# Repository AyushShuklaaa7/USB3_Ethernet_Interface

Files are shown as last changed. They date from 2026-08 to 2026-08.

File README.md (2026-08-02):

# USB 3.1 Gen 1 to Gigabit Ethernet Interface

This project is a hardware implementation of a USB 3.1 Gen 1 to Gigabit Ethernet adapter designed in KiCad. It is based on the Microchip LAN7801 USB-to-Ethernet controller and the KSZ9031RNX Gigabit Ethernet PHY.

The goal of this project was to gain practical experience in designing a high-speed PCB while following signal integrity, power integrity, and layout guidelines required for USB 3.1 and Gigabit Ethernet interfaces.

---

# Overview

The LAN7801 acts as the USB 3.1 Gen 1 bridge and Ethernet MAC, converting 5 Gbps USB SuperSpeed data into a 125 MHz RGMII interface. The KSZ9031RNX then converts the RGMII data into standard Gigabit Ethernet signals that are transmitted through the RJ45 MagJack.

The design uses dedicated 3.3V and 1.2V power rails. Instead of using an external 1.2V regulator, the KSZ9031RNX's integrated LDO controller is used with a DMG2301L P-channel MOSFET to generate the PHY core supply, reducing the overall component count.

A 25 MHz ABM8G crystal provides the reference clock for both devices.

---

# PCB Layout

### Top Layer

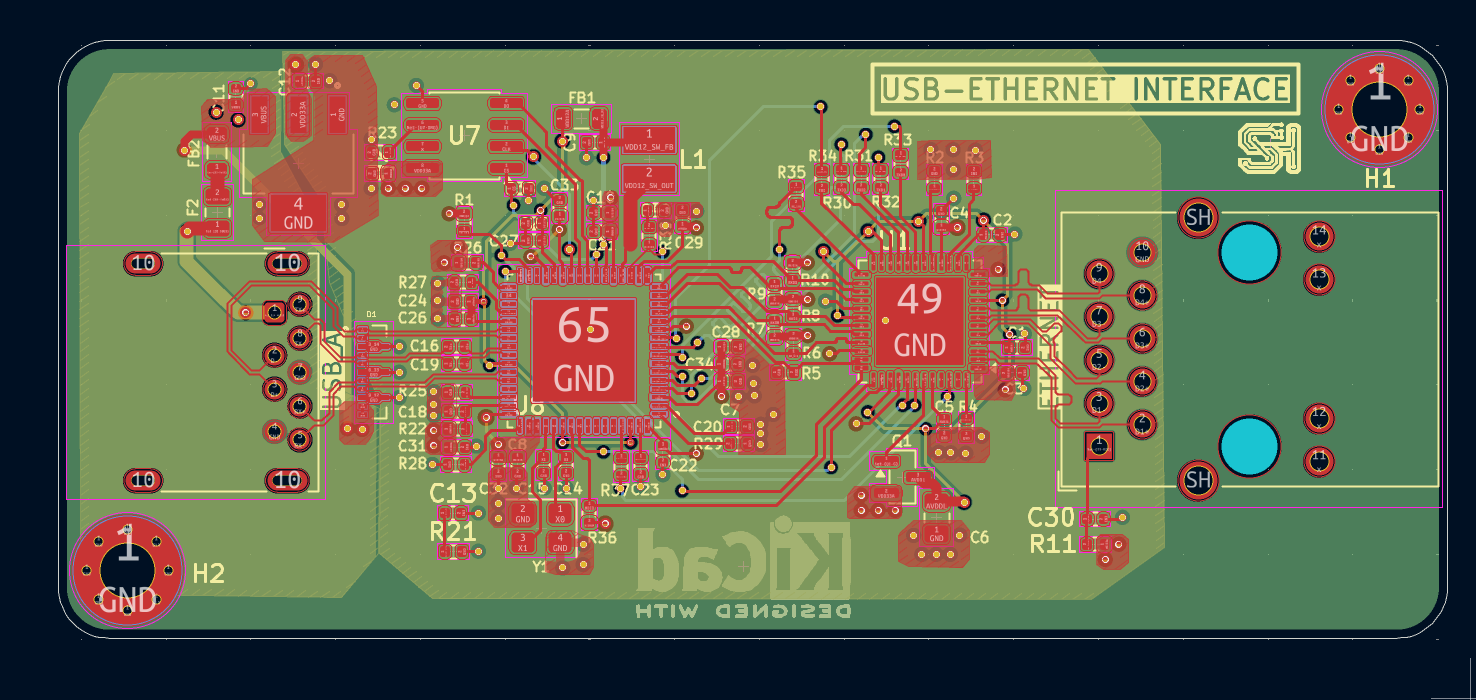
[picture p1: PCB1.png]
Top Layer


---

### Bottom Layer

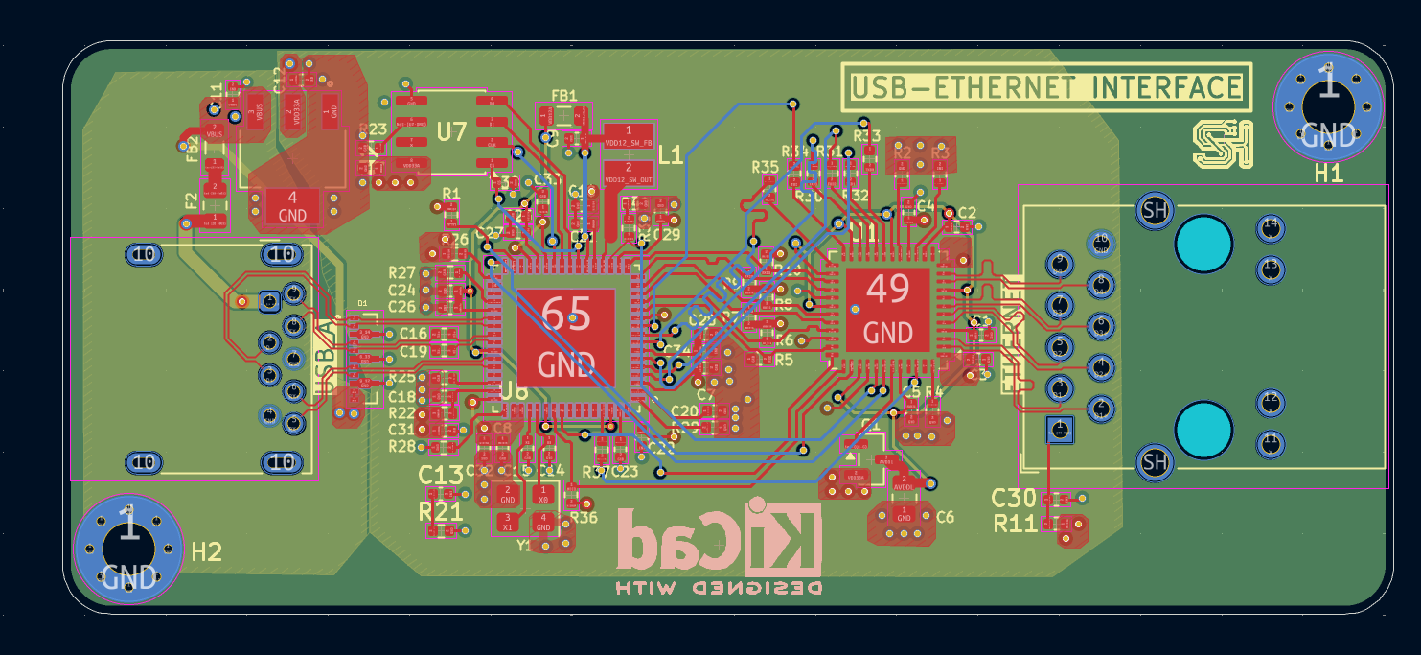
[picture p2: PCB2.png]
Bottom Layer


---

### 3D View

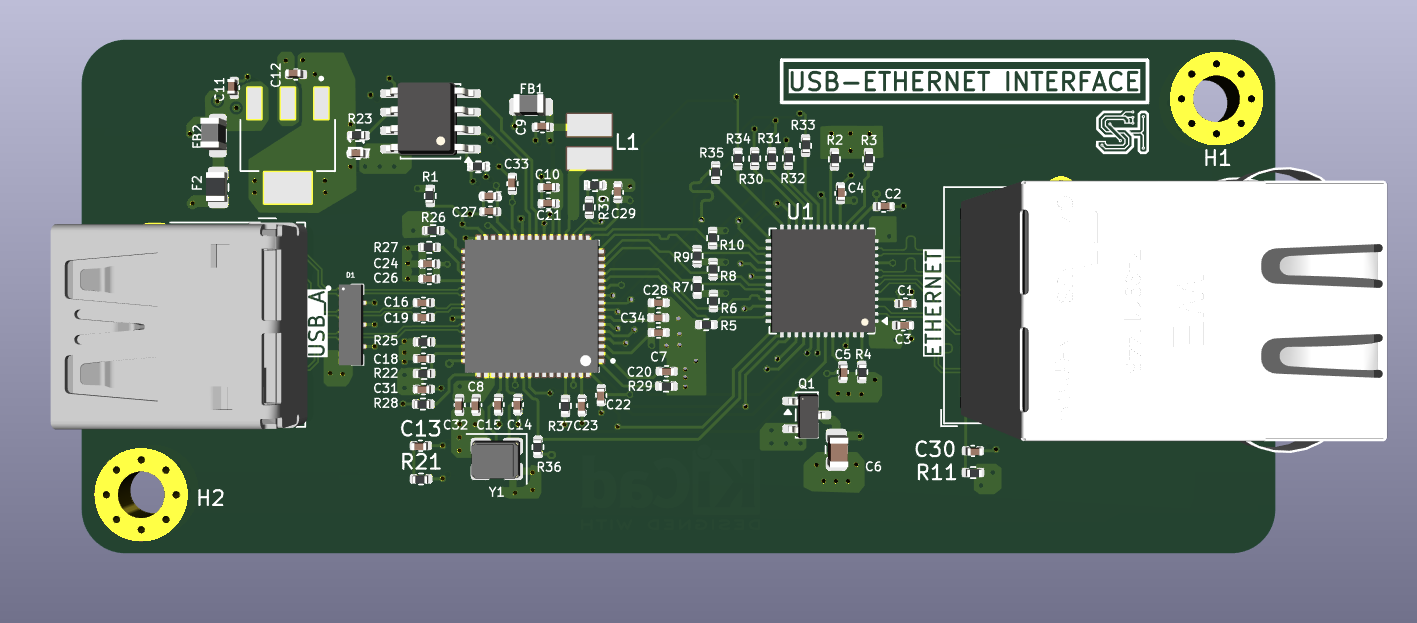
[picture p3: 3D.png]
3D View


---

# Hardware Block Diagram

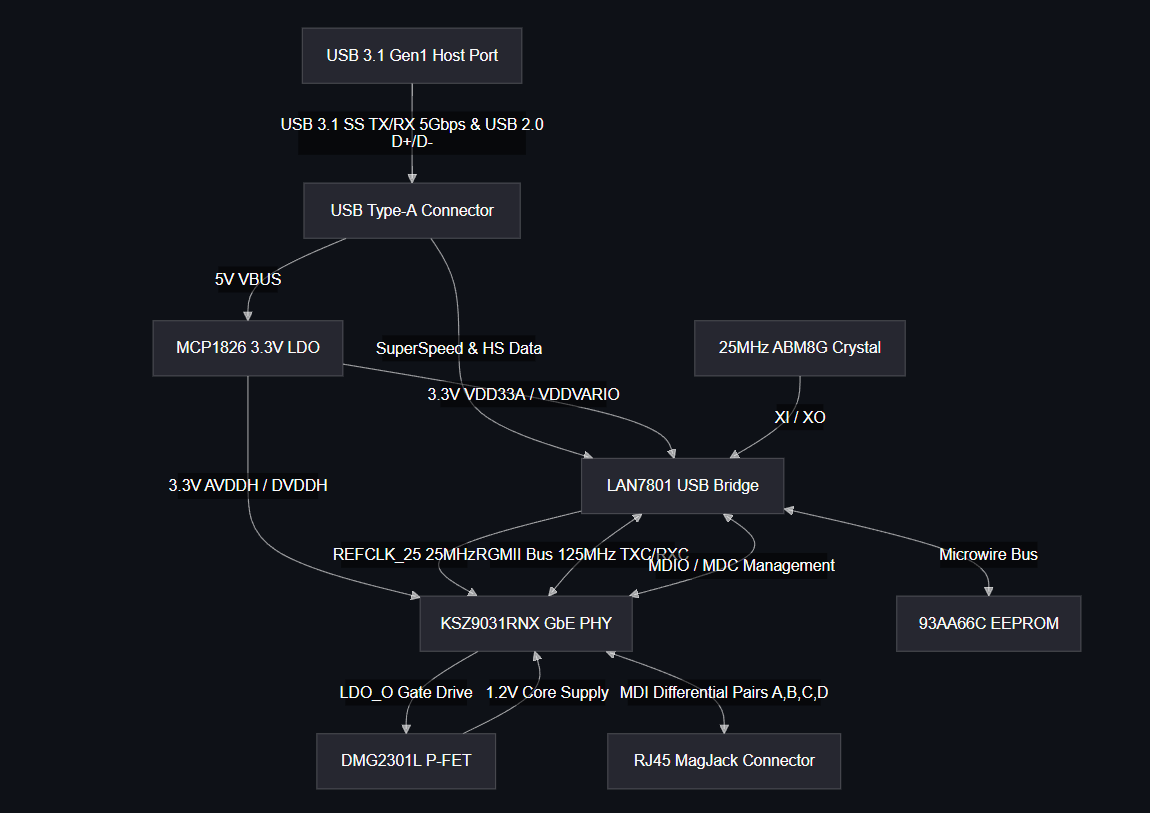
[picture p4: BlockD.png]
Block Diagram


The USB Type-A connector interfaces with the LAN7801 controller. The controller communicates with the KSZ9031RNX Gigabit PHY over the RGMII interface, while MDIO/MDC is used for PHY configuration. The PHY then drives the RJ45 MagJack to provide a standard Gigabit Ethernet connection.

---

# Design Approach

The project started by studying the LAN7801 and KSZ9031RNX datasheets along with the manufacturer's reference designs to understand the required interfaces, power supplies, clocking, and layout recommendations.

After completing the schematic, component placement was planned carefully to keep high-speed signal paths as short as possible. The USB controller was placed close to the USB connector, while the Ethernet PHY was positioned near the RJ45 MagJack to minimize RGMII routing.

During PCB layout, the main focus was maintaining signal integrity by following controlled impedance routing, differential pair routing, length matching, proper grounding, and good decoupling practices.

---

# Main Components

| Component | Description |
|---|---|
| LAN7801 | USB 3.1 Gen 1 to Gigabit Ethernet Controller |
| KSZ9031RNX | Gigabit Ethernet PHY |
| ABM8G | 25 MHz Crystal Oscillator |
| DMG2301L | P-Channel MOSFET |
| RJ45 MagJack | Gigabit Ethernet Connector |
| USB Type-A Connector | USB SuperSpeed Interface |

---

# PCB Design Highlights

- 4-layer PCB stack-up
- USB 3.1 SuperSpeed differential pair routing
- 125 MHz RGMII interface routing
- Controlled impedance traces
- Differential pair length matching
- Continuous ground plane
- Proper decoupling capacitor placement
- ESD protection for external interfaces
- Power integrity considerations

---

# Design Challenges

Some of the key challenges while designing this PCB were:

- Routing USB SuperSpeed differential pairs while maintaining impedance.
- Length matching the RGMII interface.
- Placing decoupling capacitors close to the IC power pins.
- Maintaining clean return current paths using continuous ground planes.
- Planning the component placement to minimize high-speed routing complexity.
- Following the layout recommendations provided in the component datasheets.

---

# Software Used

- KiCad
- Saturn PCB Toolkit
- Pspice

---

# Future Improvements

- Generate complete fabrication outputs (Gerber, Drill, BOM and Pick & Place files).
- Perform impedance verification using PCB stack-up calculations.
- Prototype and validate the hardware with functional testing.
- Perform USB and Ethernet compliance testing.

---

# Author

**Ayush Shukla**

B.Tech Electronics & Telecommunication Engineering

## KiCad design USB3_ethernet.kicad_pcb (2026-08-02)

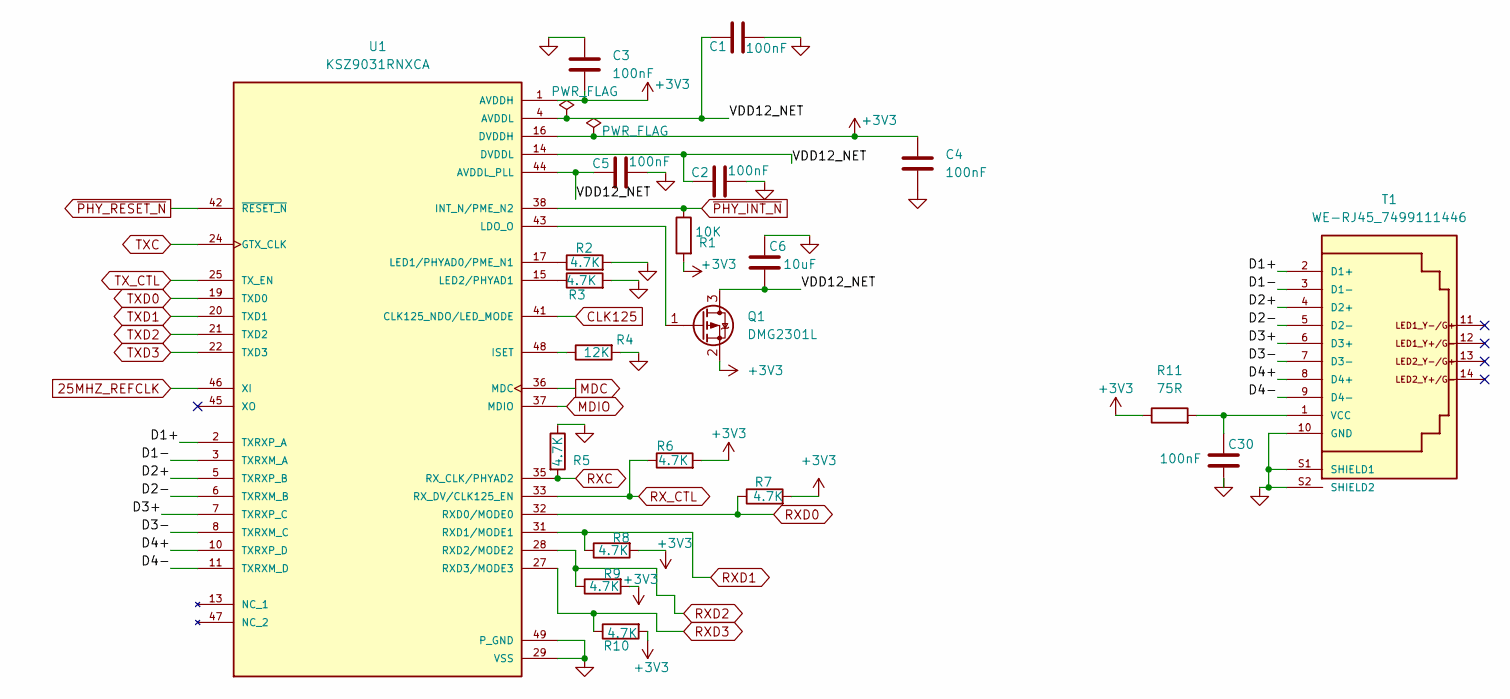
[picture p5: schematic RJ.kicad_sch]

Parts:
C1, C2, C3, C4, C5, C30: 100nF; C_0402_1005Metric
C6: 10uF; C_0805_2012Metric
Q1: DMG2301L; SOT-23
R1: 10K; R_0402_1005Metric
R2, R3, R5, R6, R7, R8, R9, R10: 4.7K; R_0402_1005Metric
R4: 12K; R_0402_1005Metric
R11: 75R; R_0402_1005Metric
T1: WE-RJ45_7499111446; RJ45_Wuerth_7499111446_Horizontal
U1: KSZ9031RNXCA; QFN-48-1EP_7x7mm_P0.5mm_EP5.15x5.15mm; PARTREV 07-09-24

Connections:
25MHZ_REFCLK: U1.46 (XI); also elsewhere on the board
/RJ/D1+: T1.2 (D1+), U1.2 (TXRXP_A); also elsewhere on the board
/RJ/D1-: T1.3 (D1-), U1.3 (TXRXM_A); also elsewhere on the board
/RJ/D2+: T1.4 (D2+), U1.5 (TXRXP_B); also elsewhere on the board
/RJ/D2-: T1.5 (D2-), U1.6 (TXRXM_B); also elsewhere on the board
/RJ/D3+: T1.6 (D3+), U1.7 (TXRXP_C); also elsewhere on the board
/RJ/D3-: T1.7 (D3-), U1.8 (TXRXM_C); also elsewhere on the board
/RJ/D4+: T1.8 (D4+), U1.10 (TXRXP_D); also elsewhere on the board
/RJ/D4-: T1.9 (D4-), U1.11 (TXRXM_D); also elsewhere on the board
AVDDL: C1.1, C2.1, C5.1, C6.2, Q1.3 (D), U1.4 (AVDDL), U1.9 (AVDDL), U1.14 (DVDDL), U1.18 (DVDDL), U1.23 (DVDDL), U1.26 (DVDDL), U1.30 (DVDDL), U1.39 (DVDDL), U1.44 (AVDDL_PLL)
CLK125: U1.41 (CLK125_NDO/LED_MODE); also elsewhere on the board
MDC: U1.36 (MDC); also elsewhere on the board
MDIO: U1.37 (MDIO); also elsewhere on the board
unnamed: Q1.1 (G), U1.43 (LDO_O)
unnamed 34: C30.1, R11.2, T1.1 (VCC); also elsewhere on the board
unnamed: R4.1, U1.48 (ISET)
unnamed: R2.1, U1.17 (LED1/PHYAD0/PME_N1)
unnamed: R3.1, U1.15 (LED2/PHYAD1)
RXC: R5.2, U1.35 (RX_CLK/PHYAD2); also elsewhere on the board
RXD0: R7.1, U1.32 (RXD0/MODE0); also elsewhere on the board
RXD1: R8.1, U1.31 (RXD1/MODE1); also elsewhere on the board
RXD2: R9.1, U1.28 (RXD2/MODE2); also elsewhere on the board
RXD3: R10.1, U1.27 (RXD3/MODE3); also elsewhere on the board
RX_CTL: R6.1, U1.33 (RX_DV/CLK125_EN); also elsewhere on the board
TXC: U1.24 (GTX_CLK); also elsewhere on the board
TXD0: U1.19 (TXD0); also elsewhere on the board
TXD1: U1.20 (TXD1); also elsewhere on the board
TXD2: U1.21 (TXD2); also elsewhere on the board
TXD3: U1.22 (TXD3); also elsewhere on the board
TX_CTL: U1.25 (TX_EN); also elsewhere on the board
VDD33A: C3.2, C4.1, Q1.2 (S), R1.2, R6.2, R7.2, R8.2, R9.2, R10.2, R11.1, U1.1 (AVDDH), U1.12 (AVDDH), U1.16 (DVDDH), U1.34 (DVDDH), U1.40 (DVDDH); also elsewhere on the board
~PHY_INT_N: R1.1, U1.38 (INT_N/PME_N2); also elsewhere on the board
~PHY_RESET_N: U1.42 (~RESET_N); also elsewhere on the board

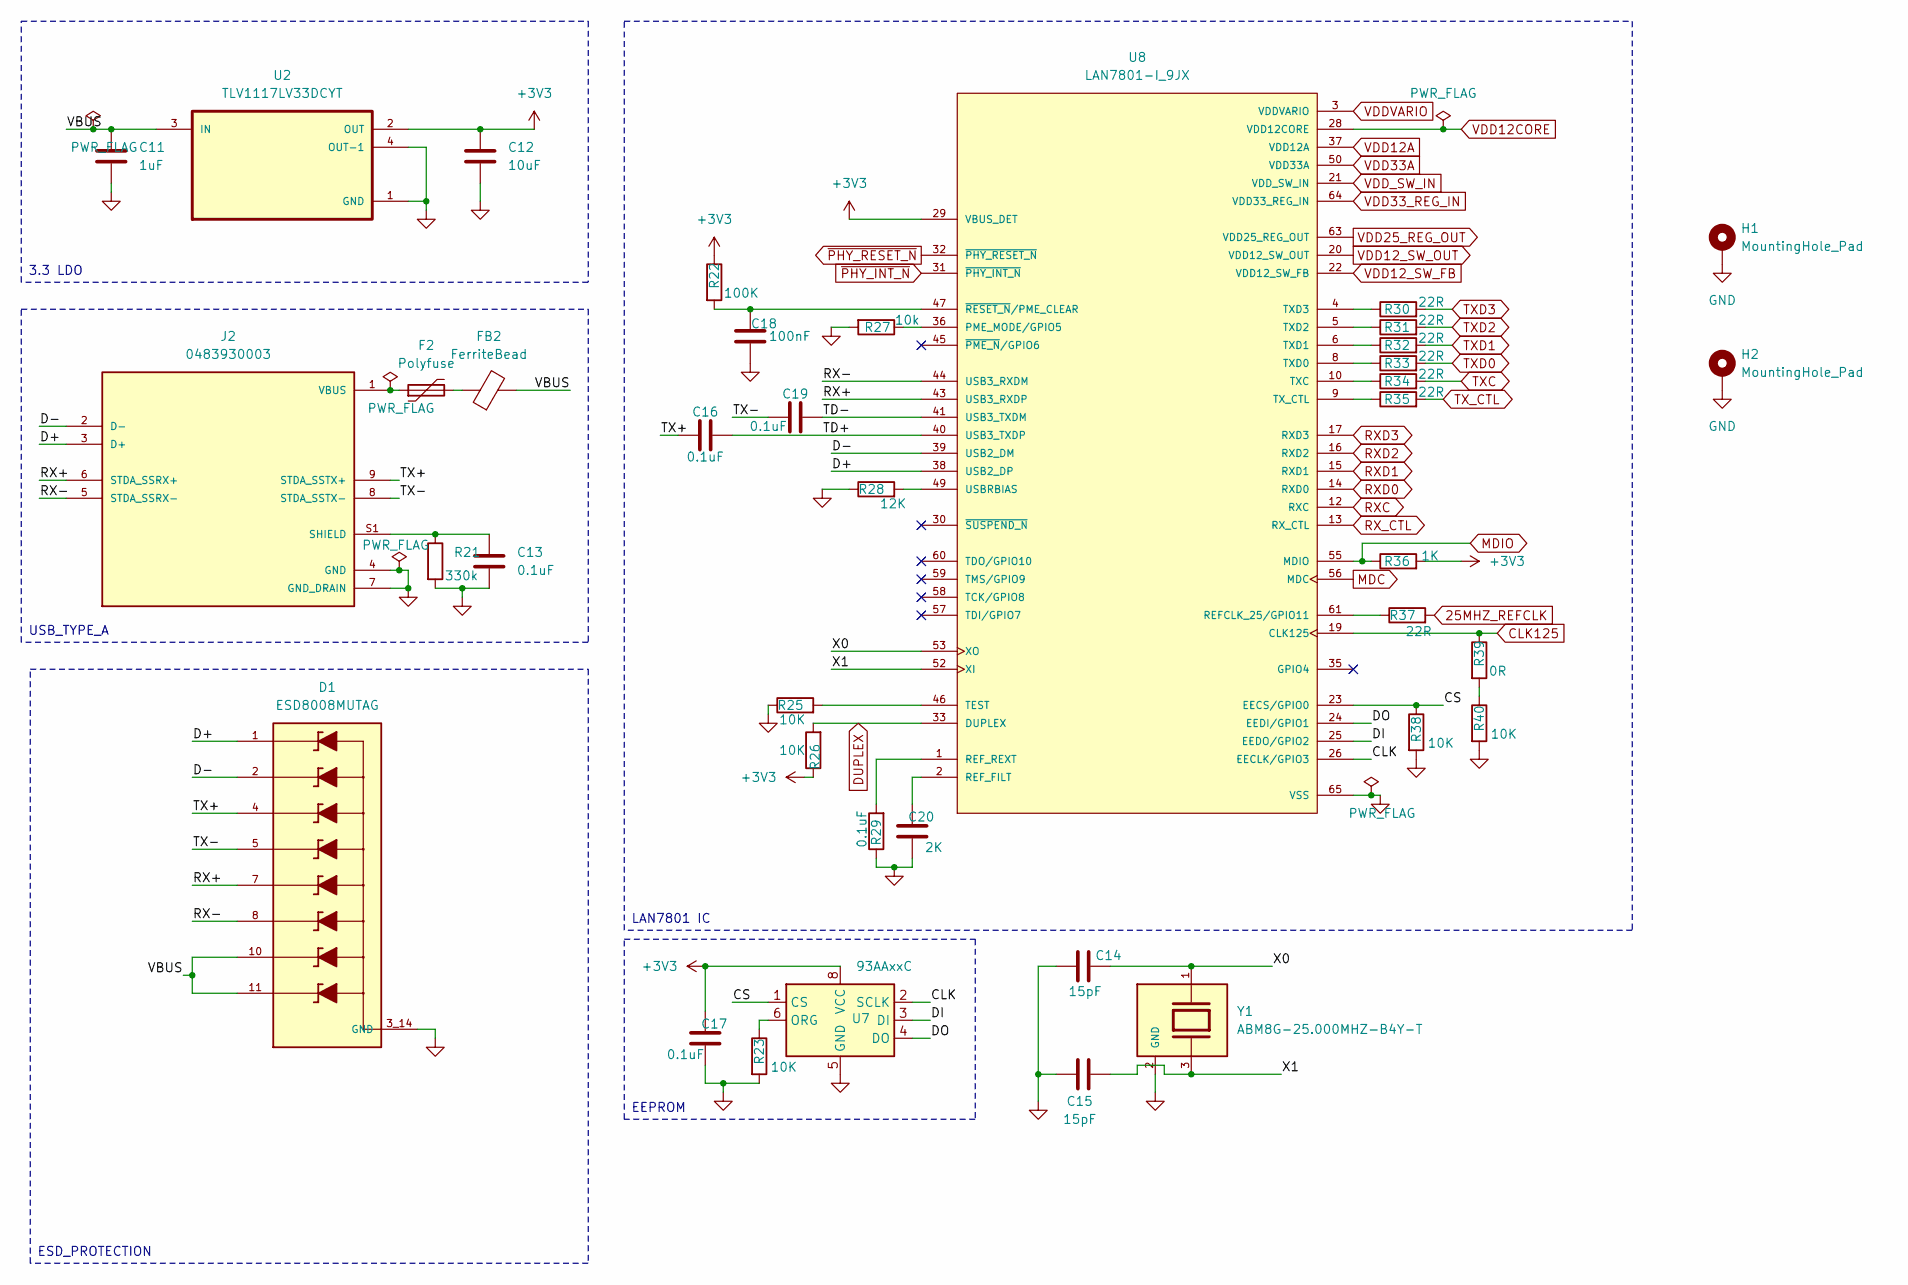
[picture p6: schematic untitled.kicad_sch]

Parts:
C11: 1uF; C_0402_1005Metric
C12: 10uF; C_0402_1005Metric
C13, C16, C17, C19: 0.1uF; C_0402_1005Metric
C14, C15: 15pF; C_0402_1005Metric
C18: 100nF; C_0402_1005Metric
C20: 2K; C_0402_1005Metric
D1: ESD8008MUTAG; DIO_ESD8008MUTAG; PARTREV 5
F2: Polyfuse; Fuse_0805_2012Metric
FB2: FerriteBead; L_0805_2012Metric
H1, H2: MountingHole_Pad; MountingHole_3.2mm_M3_Pad_Via
J2: 0483930003; USB3_A_Molex_48393-001; PARTREV A
R21: 330k; R_0402_1005Metric
R22: 100K; R_0402_1005Metric
R23, R25, R26, R38, R40: 10K; R_0402_1005Metric
R27: 10k; R_0402_1005Metric
R28: 12K; R_0402_1005Metric
R29: 0.1uF; R_0402_1005Metric
R30, R31, R32, R33, R34, R35, R37: 22R; R_0402_1005Metric
R36: 1K; R_0402_1005Metric
R39: 0R; R_0402_1005Metric
U2: TLV1117LV33DCYT; SOT230P700X180-4N
U7: 93AAxxC; SOIC-8_3.9x4.9mm_P1.27mm
U8: LAN7801-I_9JX; QFN50P900X900X100-65N_LAN7801-I_9JX; PARTREV DS00002123F; DigiKey_Part_Number LAN7801-I/9JX-ND
Y1: ABM8G-25.000MHZ-B4Y-T; Crystal_SMD_Abracon_ABM8G-4Pin_3.2x2.5mm; PARTREV 08.13.15

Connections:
25MHZ_REFCLK: R37.2; also elsewhere on the board
/USB/CLK: U7.2 (SCLK), U8.26 (EECLK/GPIO3)
/USB/CS: R38.1, U7.1 (CS), U8.23 (EECS/GPIO0)
/USB/D+: D1.1, J2.3 (D+), U8.38 (USB2_DP); also elsewhere on the board
/USB/D-: D1.2, J2.2 (D-), U8.39 (USB2_DM); also elsewhere on the board
/USB/DI: U7.3 (DI), U8.25 (EEDO/GPIO2)
/USB/DO: U7.4 (DO), U8.24 (EEDI/GPIO1)
/USB/RX+: D1.7, J2.6 (STDA_SSRX+), U8.43 (USB3_RXDP); also elsewhere on the board
/USB/RX-: D1.8, J2.5 (STDA_SSRX-), U8.44 (USB3_RXDM); also elsewhere on the board
/USB/TD+: C16.1, U8.40 (USB3_TXDP)
/USB/TD-: C19.2, U8.41 (USB3_TXDM)
/USB/TX+: C16.2, D1.4, J2.9 (STDA_SSTX+); also elsewhere on the board
/USB/TX-: C19.1, D1.5, J2.8 (STDA_SSTX-); also elsewhere on the board
/USB/VBUS: C11.1, D1.10, D1.11, FB2.2, U2.3 (IN)
/USB/X0: C14.1, U8.53 (XO), Y1.1
/USB/X1: C15.1, U8.52 (XI), Y1.3
CLK125: R39.1, U8.19 (CLK125); also elsewhere on the board
DUPLEX: R26.2, U8.33 (DUPLEX)
MDC: U8.56 (MDC); also elsewhere on the board
MDIO: R36.1, U8.55 (MDIO); also elsewhere on the board
unnamed: C13.1, J2.S1 (SHIELD), J2.S2 (SHIELD), J2.S3 (SHIELD), J2.S4 (SHIELD), R21.1
unnamed: F2.2, FB2.1
unnamed 31: F2.1, J2.1 (VBUS); also elsewhere on the board
unnamed: R39.2, R40.1
unnamed: R23.1, U7.6 (ORG)
unnamed: R27.1, U8.36 (PME_MODE/GPIO5)
unnamed: R37.1, U8.61 (REFCLK_25/GPIO11)
unnamed: C20.1, U8.2 (REF_FILT)
unnamed: R29.2, U8.1 (REF_REXT)
unnamed: R25.2, U8.46 (TEST)
unnamed: R34.1, U8.10 (TXC)
unnamed: R33.1, U8.8 (TXD0)
unnamed: R32.1, U8.6 (TXD1)
unnamed: R31.1, U8.5 (TXD2)
unnamed: R30.1, U8.4 (TXD3)
unnamed: R35.1, U8.9 (TX_CTL)
unnamed: R28.2, U8.49 (USBRBIAS)
unnamed: C18.2, R22.2, U8.47 (~RESET_N/PME_CLEAR)
RXC: U8.12 (RXC); also elsewhere on the board
RXD0: U8.14 (RXD0); also elsewhere on the board
RXD1: U8.15 (RXD1); also elsewhere on the board
RXD2: U8.16 (RXD2); also elsewhere on the board
RXD3: U8.17 (RXD3); also elsewhere on the board
RX_CTL: U8.13 (RX_CTL); also elsewhere on the board
TXC: R34.2; also elsewhere on the board
TXD0: R33.2; also elsewhere on the board
TXD1: R32.2; also elsewhere on the board
TXD2: R31.2; also elsewhere on the board
TXD3: R30.2; also elsewhere on the board
TX_CTL: R35.2; also elsewhere on the board
VDD12A: U8.28 (VDD12CORE), U8.37 (VDD12A), U8.42 (VDD12A), U8.54 (VDD12CORE), U8.62 (VDD12A); also elsewhere on the board
VDD12_SW_FB: U8.22 (VDD12_SW_FB); also elsewhere on the board
VDD12_SW_OUT: U8.20 (VDD12_SW_OUT); also elsewhere on the board
VDD25_REG_OUT: U8.63 (VDD25_REG_OUT); also elsewhere on the board
VDD33A: C12.1, C17.1, R22.1, R26.1, R36.2, U2.2 (OUT), U7.8 (VCC), U8.3 (VDDVARIO), U8.7 (VDDVARIO), U8.11 (VDDVARIO), U8.18 (VDDVARIO), U8.21 (VDD_SW_IN), U8.27 (VDDVARIO), U8.29 (VBUS_DET), U8.48 (VDDVARIO), U8.50 (VDD33A), U8.51 (VDDVARIO), U8.64 (VDD33_REG_IN); also elsewhere on the board
~PHY_INT_N: U8.31 (~PHY_INT_N); also elsewhere on the board
~PHY_RESET_N: U8.32 (~PHY_RESET_N); also elsewhere on the board

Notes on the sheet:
LAN7801 IC
3.3 LDO
ESD_PROTECTION
USB_TYPE_A
EEPROM

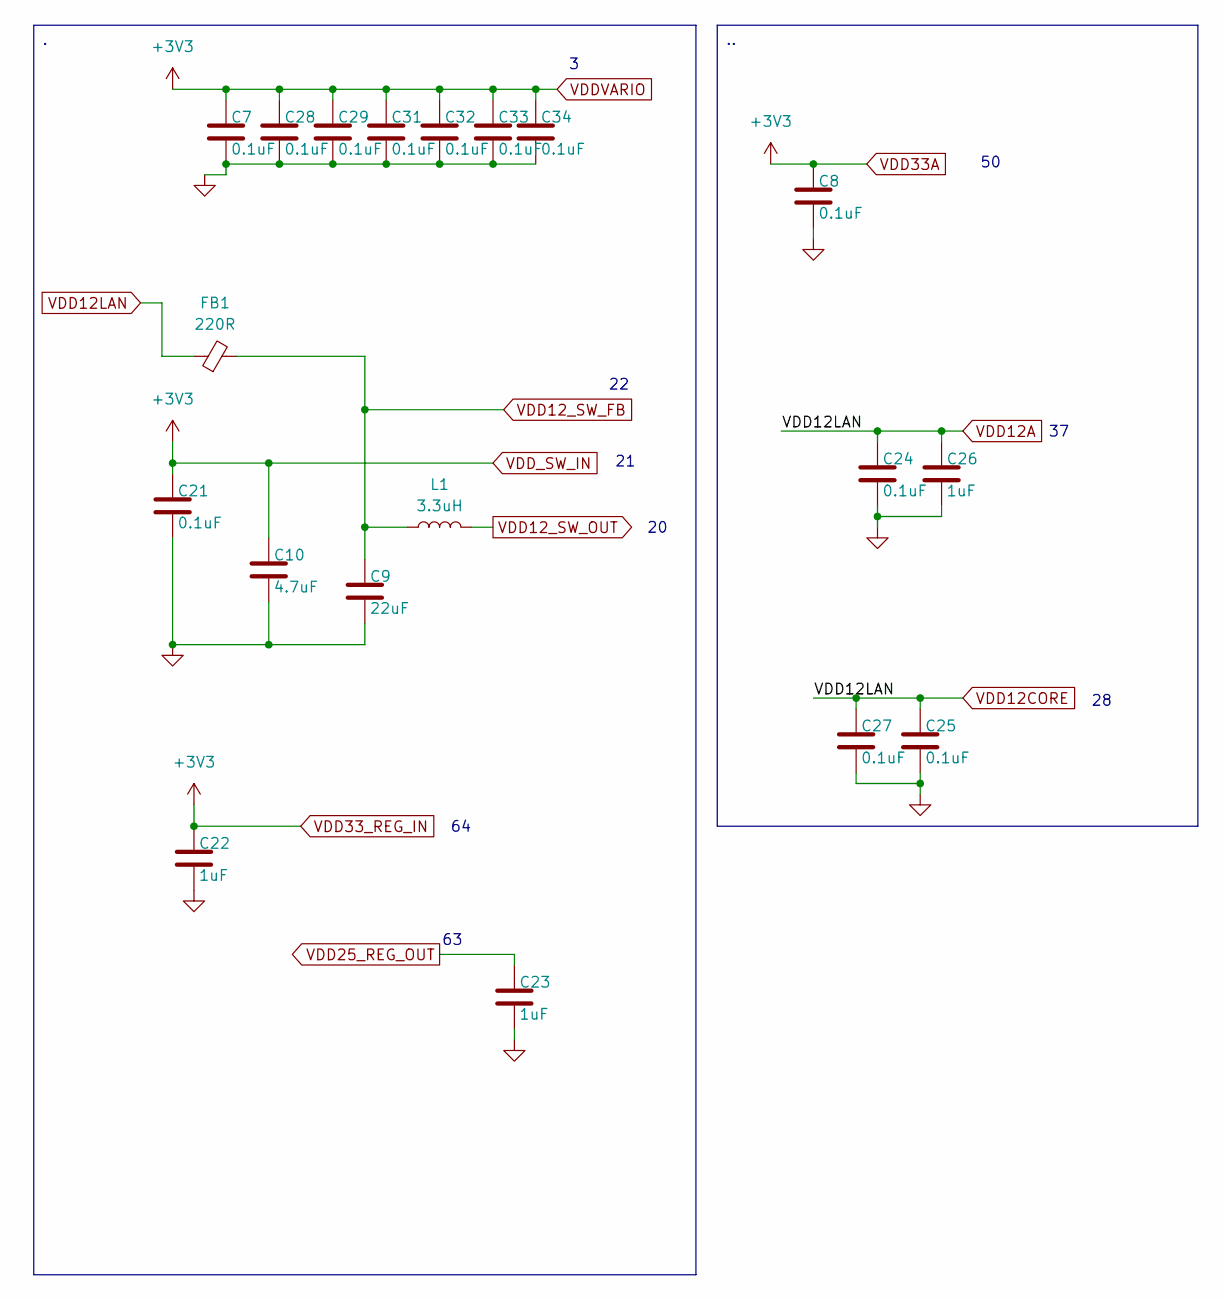
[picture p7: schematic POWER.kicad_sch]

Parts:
C7, C8, C21, C24, C25, C27, C28, C29, C31, C32, C33, C34: 0.1uF; C_0402_1005Metric
C9: 22uF; C_0402_1005Metric
C10: 4.7uF; C_0402_1005Metric
C22, C23, C26: 1uF; C_0402_1005Metric
FB1: 220R; L_0805_2012Metric
L1: 3.3uH; IND_ME3220-102MLB

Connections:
VDD12A: C24.1, C25.1, C26.1, C27.1, FB1.1; also elsewhere on the board
VDD12_SW_FB: C9.1, FB1.2, L1.1; also elsewhere on the board
VDD12_SW_OUT: L1.2; also elsewhere on the board
VDD25_REG_OUT: C23.1; also elsewhere on the board
VDD33A: C7.1, C8.1, C10.1, C21.1, C22.1, C28.1, C29.1, C31.1, C32.1, C33.1, C34.1; also elsewhere on the board

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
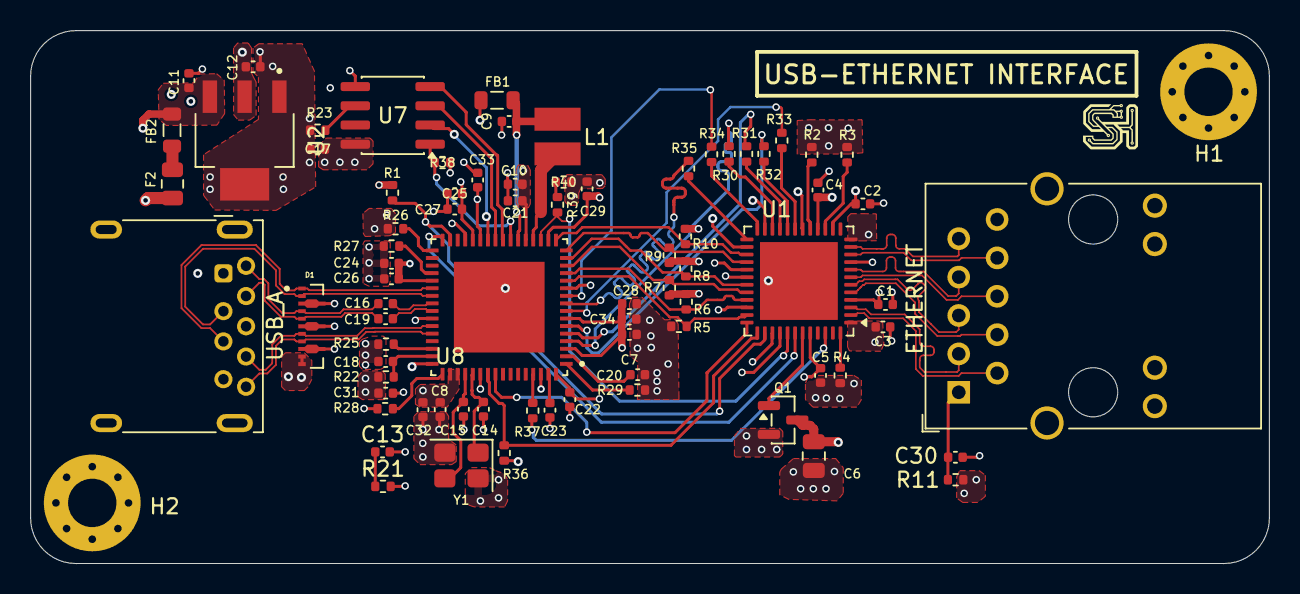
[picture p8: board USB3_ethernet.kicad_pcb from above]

Board: 4 copper layers, 81.9 x 35.3 mm, 79 parts (0 on the bottom side), 72 nets.

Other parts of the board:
ETHERNET : WE-RJ45_7499111446; RJ45_Wuerth_7499111446_Horizontal
USB_A: 0483930003; USB3_A_Molex_48393-001

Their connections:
/RJ/D1+: ETHERNET.2 (D1+); also elsewhere on the board
/RJ/D1-: ETHERNET.3 (D1-); also elsewhere on the board
/RJ/D2+: ETHERNET.4 (D2+); also elsewhere on the board
/RJ/D2-: ETHERNET.5 (D2-); also elsewhere on the board
/RJ/D3+: ETHERNET.6 (D3+); also elsewhere on the board
/RJ/D3-: ETHERNET.7 (D3-); also elsewhere on the board
/RJ/D4+: ETHERNET.8 (D4+); also elsewhere on the board
/RJ/D4-: ETHERNET.9 (D4-); also elsewhere on the board
/USB/D+: USB_A.3 (D+); also elsewhere on the board
/USB/D-: USB_A.2 (D-); also elsewhere on the board
/USB/RX+: USB_A.6 (STDA_SSRX+); also elsewhere on the board
/USB/RX-: USB_A.5 (STDA_SSRX-); also elsewhere on the board
/USB/TX+: USB_A.9 (STDA_SSTX+); also elsewhere on the board
/USB/TX-: USB_A.8 (STDA_SSTX-); also elsewhere on the board
unnamed 31: USB_A.1 (VBUS); also elsewhere on the board
unnamed 34: ETHERNET.1 (VCC); also elsewhere on the board
